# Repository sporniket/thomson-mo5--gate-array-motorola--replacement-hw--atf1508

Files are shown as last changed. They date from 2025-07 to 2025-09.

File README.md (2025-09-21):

# Replacement of the Motorola gate array for the Thomson MO5 by Microchip ATF1508

> [WARNING] Please read carefully this note before using this project. It contains important facts.

Content

1. What is **Replacement of the Motorola gate array for the Thomson MO5 by Microchip ATF1508**, and when to use it ?
2. What should you know before using **Replacement of the Motorola gate array for the Thomson MO5 by Microchip ATF1508** ?
3. How to use **Replacement of the Motorola gate array for the Thomson MO5 by Microchip ATF1508** ?
4. Known issues
5. Miscellanous

## 1. What is **Replacement of the Motorola gate array for the Thomson MO5 by Microchip ATF1508**, and when to use it ?

**Replacement of the Motorola gate array for the Thomson MO5 by Microchip ATF1508** is a hardware project to replace the original Motorola Gate Array of the Thomson MO5 8-bit computer, using an ATF1508.

### Licence

**Replacement of the Motorola gate array for the Thomson MO5 by Microchip ATF1508** is published under the Creative Commons CC0 license. You can find a copy of the licence there : https://creativecommons.org/publicdomain/zero/1.0/legalcode

You can copy, modify, distribute and perform the work, even for commercial purposes, all without asking permission.

**Replacement of the Motorola gate array for the Thomson MO5 by Microchip ATF1508** is distributed in the hope that it will be useful, but WITHOUT ANY WARRANTY; without even the implied warranty of MERCHANTABILITY or FITNESS FOR A PARTICULAR PURPOSE.

### Release notes

#### Version 1.0.0

Initial release.

> Note : I did something with the 2×4 header connector footprint, believing that it would held better the connector, but it does not help at all, sorry. I will fix this when I have time, it is just a bit inconvenient.

## 2. What should you know before using **Replacement of the Motorola gate array for the Thomson MO5 by Microchip ATF1508** ?

**Replacement of the Motorola gate array for the Thomson MO5 by Microchip ATF1508** is made using Kicad.

> Do not use **Replacement of the Motorola gate array for the Thomson MO5 by Microchip ATF1508** if this project is not suitable for your project.

### Fusemap file to program the ATF1508

You will find the SVF file in the `fusemap` folder.

### Bill Of Material (BOM)

|Item|Quantity|Designators|Type|Reference|Manufacturer|Link|
|---|---|---|---|---|---|---|
|1|8|`C1`, `C2`, `C3`, `C4`, `C5`, `C6`, `C7`, `C8`|Capacitor 0.22uF SMD 0603|220nF 25VDC 0603|N/A|[lcsc](https://lcsc.com/product-detail/Multilayer-Ceramic-Capacitors-MLCC-SMD-SMT_YAGEO-CC0603JRX7R8BB224_C519574.html) [rs-particuliers](https://rs-particuliers.com/Product.aspx?Product=485771)|
|2|1|`J1`|Pin header 2×4 pitch 100 mils||N/A|[lcsc](https://lcsc.com/product-detail/Pin-Headers_Megastar-ZX-PZ2-54-2-4PZZ_C7501275.html)|
|3|1|`J2`|Pin stripes 9 pins and 8 pins, pitch 100 mils||N/A|[lcsc 9 pins](https://lcsc.com/product-detail/Pin-Headers_HCTL-PZ254-1-09-Z-C_C5156436.html) [lcsc 8 pins](https://lcsc.com/product-detail/Pin-Headers_HCTL-PZ254-1-08-Z-C_C5156435.html)|
|4|1|`J3`|Pin header 2×1 pitch 100 mils||N/A|[lcsc](https://lcsc.com/product-detail/Pin-Headers_XFCN-PZ254V-11-02P_C492401.html)|
|5|3|`R1`, `R2`, `R3`|Resistor 4K7 SMD 0603|Resistor Thick Film 0603 1% 4k7|N/A|[lcsc](https://lcsc.com/product-detail/Chip-Resistor-Surface-Mount_VISHAY-RCS06034K70FKEA_C2078630.html) [rs-particuliers](https://rs-particuliers.com/Product.aspx?Product=2432188)|
|6|1|`U1`|CPLD ATF1508AS|ATF1508AS-10AU100|Microchip|[lcsc](https://lcsc.com/product-detail/Programmable-Logic-Device-CPLDs-FPGAs_MICROCHIP-ATF1508AS-10AU100_C31179.html) [rs-particuliers](https://rs-particuliers.com/Product.aspx?Product=1773660)|

## 3. How to use **Replacement of the Motorola gate array for the Thomson MO5 by Microchip ATF1508** ?

### From sources

To get the latest available work, one must clone the git repository, build and install the package.

	git clone https://github.com/sporniket/thomson-mo5--gate-array-motorola--replacement-hw--atf1508.git

Then, open the project with Kicad.

## 4. Known issues
See the [project issues](https://github.com/sporniket/thomson-mo5--gate-array-motorola--replacement-hw--atf1508/issues) page.

## 5. Miscellanous

### Report issues
Use the [project issues](https://github.com/sporniket/thomson-mo5--gate-array-motorola--replacement-hw--atf1508/issues) page.

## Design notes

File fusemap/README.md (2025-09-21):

# SVF fusemap

Unfortunately, the VHDL project that reproduces the behaviour of the original 
gate-array is not publicly available. Only the resulting SVF file is given.

As a reference, the quartus file is also provided.

## Programming the ATF1508

### Hardware setup

I use an FT323H usb dongle and a JTAG link to perform the programming.

For easier handling, there is a project to hold the FT232H module, the gate-array replacement. And it has
a witness LED that blinks when the programming is succesful, driven by the E signal (1MHz clock generated
by the gate array).

See https://github.com/sporniket/thomson-mo5--gate-array-development-board

## Using openOCD 

```sh
openocd -f /usr/share/openocd/scripts/interface/ftdi/um232h.cfg \
  -c "adapter speed 400" \
  -c "transport select jtag" \
  -c "jtag newtap ATF1508AS tap -irlen 3 -expected-id 0x0150803f" \
  -c init \
  -c "svf gate-array--motorola.svf quiet progress" \
  -c "sleep 200" \
  -c shutdown
```

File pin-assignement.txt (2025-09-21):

Pin Name/Usage               : Location  : Dir.   : I/O Standard      : Voltage : I/O Bank  : User Assignment
-------------------------------------------------------------------------------------------------------------
RESERVED                     : 1         :        :                   :         :           :                
RESERVED                     : 2         :        :                   :         :           :                
VCCIO                        : 3         : power  :                   : 5.0V    :           :                
TDI                          : 4         : input  : TTL               :         :           : Y              
INILText                     : 5         : output : TTL               :         :           : Y              
RESERVED                     : 6         :        :                   :         :           :                
SYNLText                     : 7         : output : TTL               :         :           : Y              
RESERVED                     : 8         :        :                   :         :           :                
RESERVED                     : 9         :        :                   :         :           :                
RESERVED                     : 10        :        :                   :         :           :                
GND                          : 11        : gnd    :                   :         :           :                
nCASCOLext                   : 12        : output : TTL               :         :           : Y              
MAext[7]                     : 13        : output : TTL               :         :           : Y              
MAext[3]                     : 14        : output : TTL               :         :           : Y              
TMS                          : 15        : input  : TTL               :         :           : Y              
MAext[2]                     : 16        : output : TTL               :         :           : Y              
RESERVED                     : 17        :        :                   :         :           :                
VCCIO                        : 18        : power  :                   : 5.0V    :           :                
RESERVED                     : 19        :        :                   :         :           :                
MAext[1]                     : 20        : output : TTL               :         :           : Y              
MAext[0]                     : 21        : output : TTL               :         :           : Y              
nCASPText                    : 22        : output : TTL               :         :           : Y              
nRASext                      : 23        : output : TTL               :         :           : Y              
MAext[6]                     : 24        : output : TTL               :         :           : Y              
MAext[5]                     : 25        : output : TTL               :         :           : Y              
GND                          : 26        : gnd    :                   :         :           :                
MAext[4]                     : 27        : output : TTL               :         :           : Y              
RESERVED                     : 28        :        :                   :         :           :                
AdresseCPUext[12]            : 29        : input  : TTL               :         :           : Y              
AdresseCPUext[11]            : 30        : input  : TTL               :         :           : Y              
AdresseCPUext[10]            : 31        : input  : TTL               :         :           : Y              
AdresseCPUext[9]             : 32        : input  : TTL               :         :           : Y              
RESERVED                     : 33        :        :                   :         :           :                
VCCIO                        : 34        : power  :                   : 5.0V    :           :                
RESERVED                     : 35        :        :                   :         :           :                
AdresseCPUext[8]             : 36        : input  : TTL               :         :           : Y              
AdresseCPUext[7]             : 37        : input  : TTL               :         :           : Y              
GND                          : 38        : gnd    :                   :         :           :                
VCCINT                       : 39        : power  :                   : 5.0V    :           :                
RESERVED                     : 40        :        :                   :         :           :                
RESERVED                     : 41        :        :                   :         :           :                
AdresseCPUext[6]             : 42        : input  : TTL               :         :           : Y              
GND                          : 43        : gnd    :                   :         :           :                
AdresseCPUext[5]             : 44        : input  : TTL               :         :           : Y              
AdresseCPUext[4]             : 45        : input  : TTL               :         :           : Y              
AdresseCPUext[3]             : 46        : input  : TTL               :         :           : Y              
AdresseCPUext[2]             : 47        : input  : TTL               :         :           : Y              
AdresseCPUext[1]             : 48        : input  : TTL               :         :           : Y              
AdresseCPUext[0]             : 49        : input  : TTL               :         :           : Y              
DataCPUext[7]                : 50        : bidir  : TTL               :         :           : Y              
VCCIO                        : 51        : power  :                   : 5.0V    :           :                
DataCPUext[6]                : 52        : bidir  : TTL               :         :           : Y              
DataCPUext[5]                : 53        : bidir  : TTL               :         :           : Y              
DataCPUext[4]                : 54        : bidir  : TTL               :         :           : Y              
DataCPUext[3]                : 55        : bidir  : TTL               :         :           : Y              
DataCPUext[2]                : 56        : bidir  : TTL               :         :           : Y              
DataCPUext[1]                : 57        : bidir  : TTL               :         :           : Y              
DataCPUext[0]                : 58        : bidir  : TTL               :         :           : Y              
GND                          : 59        : gnd    :                   :         :           :                
RESERVED                     : 60        :        :                   :         :           :                
RESERVED                     : 61        :        :                   :         :           :                
TCK                          : 62        : input  : TTL               :         :           : Y              
RESERVED                     : 63        :        :                   :         :           :                
nCASEXText                   : 64        : output : TTL               :         :           : Y              
nEext                        : 65        : output : TTL               :         :           : Y              
VCCIO                        : 66        : power  :                   : 5.0V    :           :                
Eext                         : 67        : output : TTL               :         :           : Y              
Qext                         : 68        : output : TTL               :         :           : Y              
RESERVED                     : 69        :        :                   :         :           :                
nDATAVALIDext                : 70        : output : TTL               :         :           : Y              
RESERVED                     : 71        :        :                   :         :           :                
RESERVED                     : 72        :        :                   :         :           :                
TDO                          : 73        : output : TTL               :         :           : Y              
GND                          : 74        : gnd    :                   :         :           :                
AdresseCPUext[15]            : 75        : input  : TTL               :         :           : Y              
AdresseCPUext[14]            : 76        : input  : TTL               :         :           : Y              
AdresseCPUext[13]            : 77        : input  : TTL               :         :           : Y              
FormeExt                     : 78        : input  : TTL               :         :           : Y              
RnWext                       : 79        : input  : TTL               :         :           : Y              
nCSCOLext                    : 80        : input  : TTL               :         :           : Y              
RESERVED                     : 81        :        :                   :         :           :                
VCCIO                        : 82        : power  :                   : 5.0V    :           :                
RESERVED                     : 83        :        :                   :         :           :                
RESERVED                     : 84        :        :                   :         :           :                
StartUpResetExt              : 85        : input  : TTL               :         :           : N              
GND                          : 86        : gnd    :                   :         :           :                
H16Ext                       : 87        : input  : TTL               :         :           : Y              
GND+                         : 88        :        :                   :         :           :                
GND+                         : 89        :        :                   :         :           :                
GND+                         : 90        :        :                   :         :           :                
VCCINT                       : 91        : power  :                   : 5.0V    :           :                
RESERVED                     : 92        :        :                   :         :           :                
RESERVED                     : 93        :        :                   :         :           :                
nCSEXText                    : 94        : input  : TTL               :         :           : Y              
GND                          : 95        : gnd    :                   :         :           :                
nCSPText                     : 96        : input  : TTL               :         :           : Y              
nCKLPext                     : 97        : input  : TTL               :         :           : Y              
SYCLext                      : 98        : input  : TTL               :         :           : Y              
nPOINText                    : 99        : output : TTL               :         :           : Y              
nSUPLText                    : 100       : output : TTL               :         :           : Y

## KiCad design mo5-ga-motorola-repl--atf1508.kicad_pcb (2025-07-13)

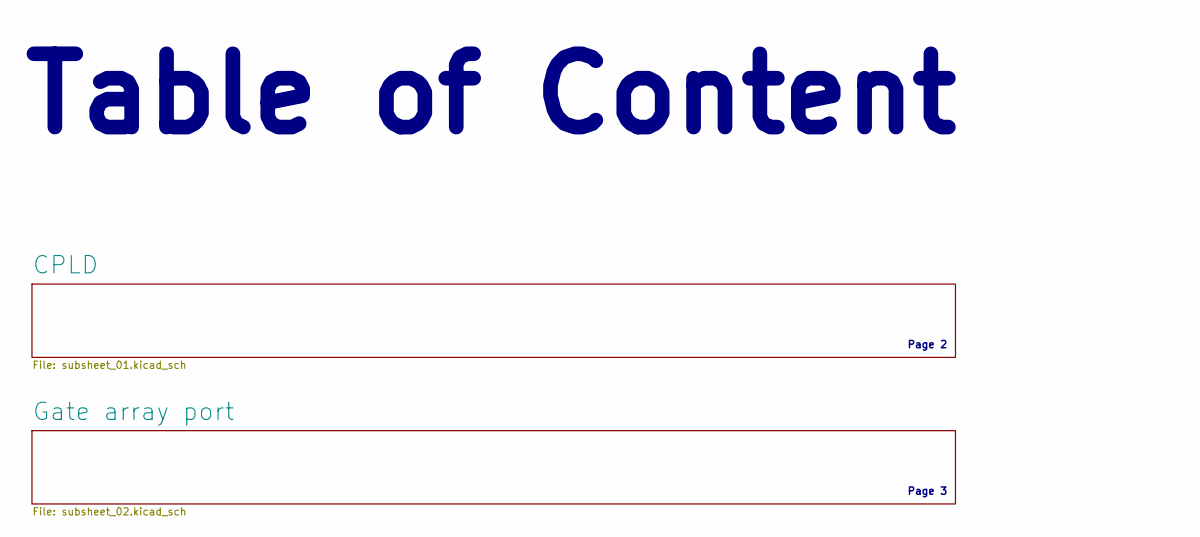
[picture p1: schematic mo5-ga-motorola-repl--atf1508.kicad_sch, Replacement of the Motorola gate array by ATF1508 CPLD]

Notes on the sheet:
Page 3
Page 2
Table of Content

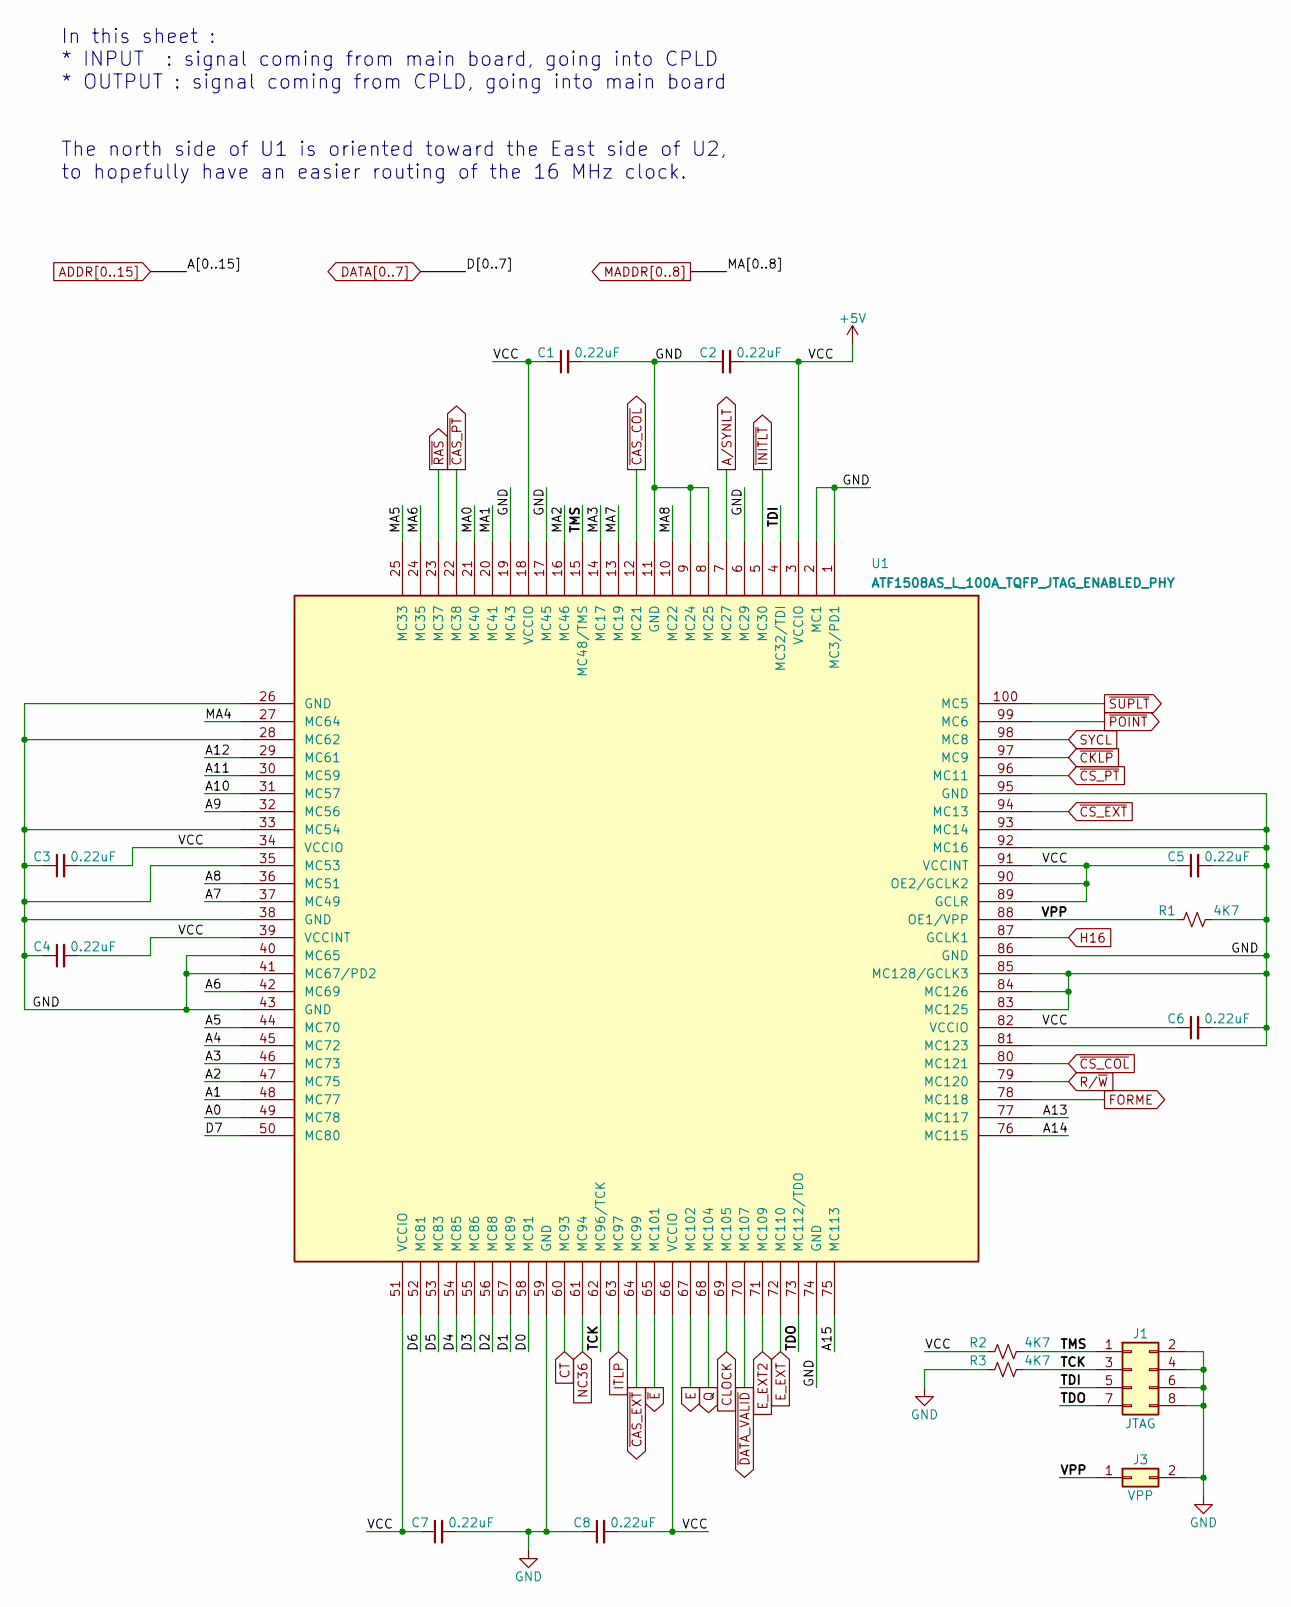
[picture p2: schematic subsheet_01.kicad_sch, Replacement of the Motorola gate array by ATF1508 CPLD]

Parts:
C1, C2, C3, C4, C5, C6, C7, C8: 0.22uF; C_0603_1608Metric_Pad1.08x0.95mm_HandSolder
J1: JTAG; PinHeader_2x04_P2.54mm_Vertical
J3: VPP; PinHeader_2x01_P2.54mm_Vertical
R1, R2, R3: 4K7; R_0603_1608Metric_Pad0.98x0.95mm_HandSolder
U1: ATF1508AS_L_100A_TQFP_JTAG_ENABLED_PHY; TQFP-100_14x14mm_P0.5mm

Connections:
+5V: C1.1, C2.2, C3.2, C4.2, C5.1, C6.1, C7.1, C8.2, R2.1, U1.3 (VCCIO), U1.18 (VCCIO), U1.34 (VCCIO), U1.39 (VCCINT), U1.51 (VCCIO), U1.66 (VCCIO), U1.82 (VCCIO), U1.89 (GCLR), U1.90 (OE2/GCLK2), U1.91 (VCCINT); also elsewhere on the board
/CPLD/TCK: J1.3, R3.2, U1.62 (MC96/TCK)
/CPLD/TDI: J1.5, U1.4 (MC32/TDI)
/CPLD/TDO: J1.7, U1.73 (MC112/TDO)
/CPLD/TMS: J1.1, R2.2, U1.15 (MC48/TMS)
/CPLD/VPP: J3.1, R1.1, U1.88 (OE1/VPP)
ADDR0: U1.49 (MC78); also elsewhere on the board
ADDR1: U1.48 (MC77); also elsewhere on the board
ADDR2: U1.47 (MC75); also elsewhere on the board
ADDR3: U1.46 (MC73); also elsewhere on the board
ADDR4: U1.45 (MC72); also elsewhere on the board
ADDR5: U1.44 (MC70); also elsewhere on the board
ADDR6: U1.42 (MC69); also elsewhere on the board
ADDR7: U1.37 (MC49); also elsewhere on the board
ADDR8: U1.36 (MC51); also elsewhere on the board
ADDR9: U1.32 (MC56); also elsewhere on the board
ADDR10: U1.31 (MC57); also elsewhere on the board
ADDR11: U1.30 (MC59); also elsewhere on the board
ADDR12: U1.29 (MC61); also elsewhere on the board
ADDR13: U1.77 (MC117); also elsewhere on the board
ADDR14: U1.76 (MC115); also elsewhere on the board
ADDR15: U1.75 (MC113); also elsewhere on the board
A/SYNLT: U1.7 (MC27); also elsewhere on the board
CLOCK: U1.69 (MC105); also elsewhere on the board
CT: U1.60 (MC93); also elsewhere on the board
DATA0: U1.58 (MC91); also elsewhere on the board
DATA1: U1.57 (MC89); also elsewhere on the board
DATA2: U1.56 (MC88); also elsewhere on the board
DATA3: U1.55 (MC86); also elsewhere on the board
DATA4: U1.54 (MC85); also elsewhere on the board
DATA5: U1.53 (MC83); also elsewhere on the board
DATA6: U1.52 (MC81); also elsewhere on the board
DATA7: U1.50 (MC80); also elsewhere on the board
E: U1.67 (MC102); also elsewhere on the board
E_EXT: U1.72 (MC110); also elsewhere on the board
E_EXT2: U1.71 (MC109); also elsewhere on the board
FORME: U1.78 (MC118); also elsewhere on the board
GND: C1.2, C2.1, C3.1, C4.1, C5.2, C6.2, C7.2, C8.1, J1.2, J1.4, J1.6, J1.8, J3.2, R1.2, R3.1, U1.1 (MC3/PD1), U1.2 (MC1), U1.6 (MC29), U1.8 (MC25), U1.9 (MC24), U1.11 (GND), U1.17 (MC45), U1.19 (MC43), U1.26 (GND), U1.28 (MC62), U1.33 (MC54), U1.35 (MC53), U1.38 (GND), U1.40 (MC65), U1.41 (MC67/PD2), U1.43 (GND), U1.59 (GND), U1.74 (GND), U1.81 (MC123), U1.83 (MC125), U1.84 (MC126), U1.85 (MC128/GCLK3), U1.86 (GND), U1.92 (MC16), U1.93 (MC14), U1.95 (GND); also elsewhere on the board
H16: U1.87 (GCLK1); also elsewhere on the board
ITLP: U1.63 (MC97); also elsewhere on the board
MADDR0: U1.21 (MC40); also elsewhere on the board
MADDR1: U1.20 (MC41); also elsewhere on the board
MADDR2: U1.16 (MC46); also elsewhere on the board
MADDR3: U1.14 (MC17); also elsewhere on the board
MADDR4: U1.27 (MC64); also elsewhere on the board
MADDR5: U1.25 (MC33); also elsewhere on the board
MADDR6: U1.24 (MC35); also elsewhere on the board
MADDR7: U1.13 (MC19); also elsewhere on the board
MADDR8: U1.10 (MC22); also elsewhere on the board
NC36: U1.61 (MC94); also elsewhere on the board
Q: U1.68 (MC104); also elsewhere on the board
R/~W: U1.79 (MC120); also elsewhere on the board
SYCL: U1.98 (MC8); also elsewhere on the board
~CAS_COL: U1.12 (MC21); also elsewhere on the board
~CAS_EXT: U1.64 (MC99); also elsewhere on the board
~CAS_PT: U1.22 (MC38); also elsewhere on the board
~CKLP: U1.97 (MC9); also elsewhere on the board
~CS_COL: U1.80 (MC121); also elsewhere on the board
~CS_EXT: U1.94 (MC13); also elsewhere on the board
~CS_PT: U1.96 (MC11); also elsewhere on the board
~DATA_VALID: U1.70 (MC107); also elsewhere on the board
~E: U1.65 (MC101); also elsewhere on the board
~INITLT: U1.5 (MC30); also elsewhere on the board
~POINT: U1.99 (MC6); also elsewhere on the board
~RAS: U1.23 (MC37); also elsewhere on the board
~SUPLT: U1.100 (MC5); also elsewhere on the board

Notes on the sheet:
In this sheet : * INPUT : signal coming from main board, going into CPLD * OUTPUT : signal coming from CPLD, going into main board
The north side of U1 is oriented toward the East side of U2, to hopefully have an easier routing of the 16 MHz clock.

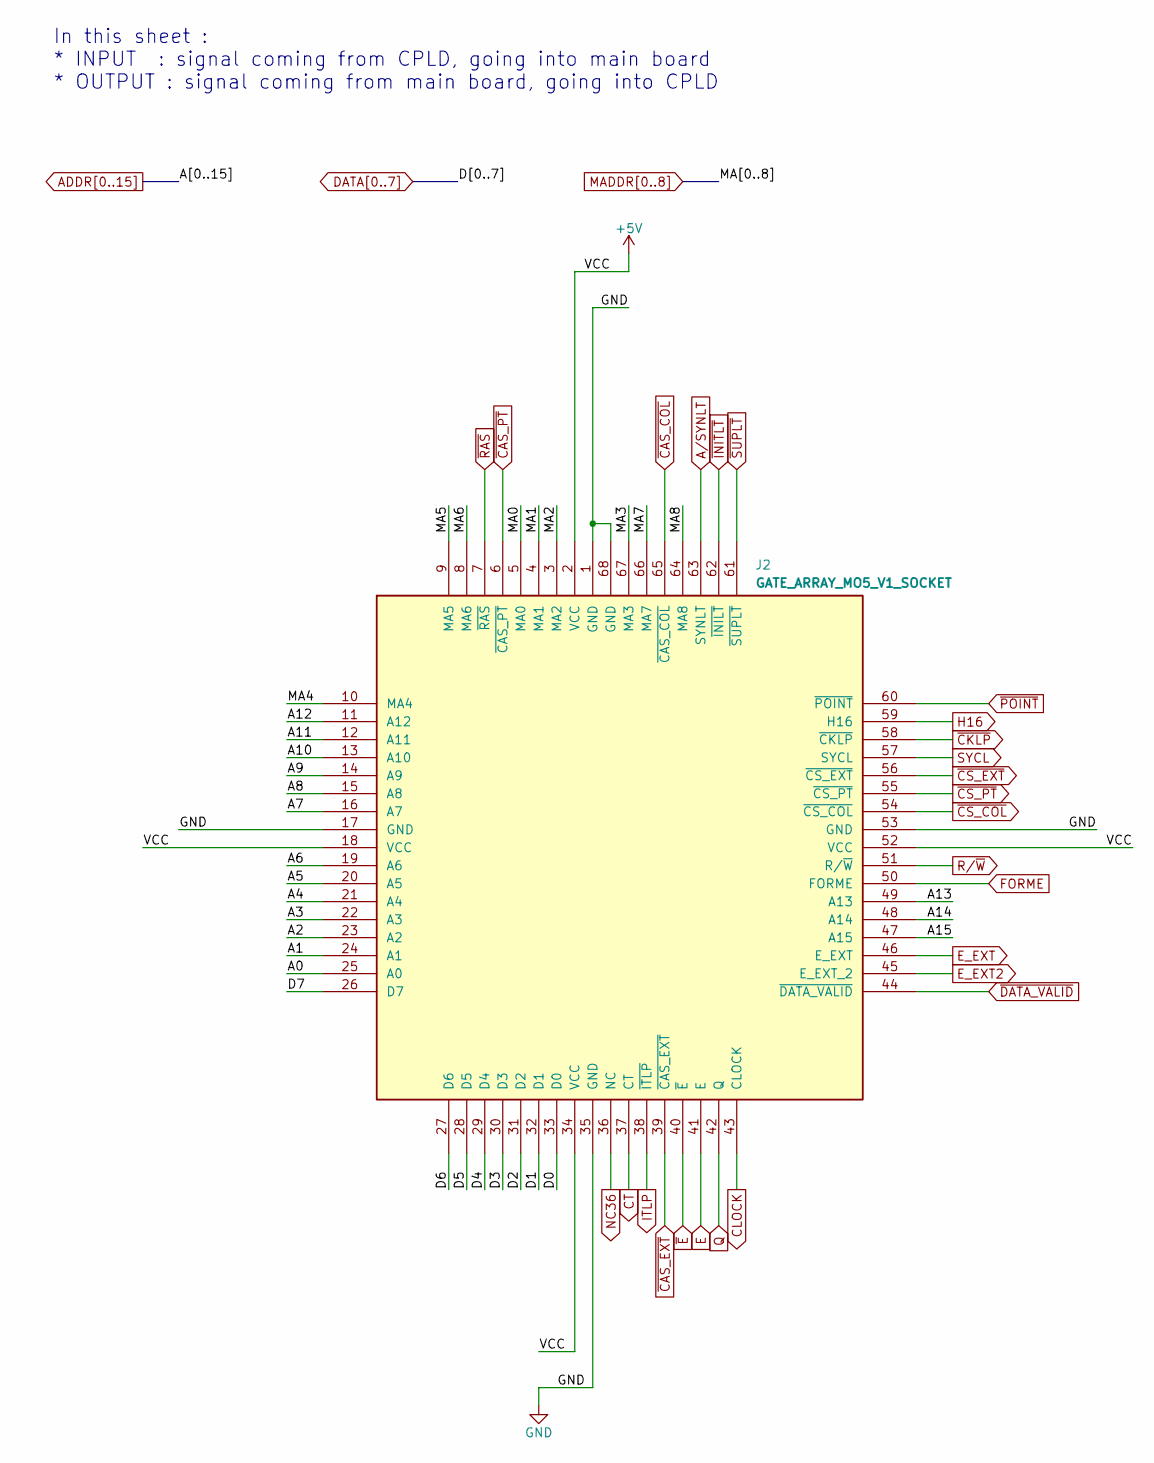
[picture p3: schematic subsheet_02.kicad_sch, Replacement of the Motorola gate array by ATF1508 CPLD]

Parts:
J2: GATE_ARRAY_MO5_V1_SOCKET; gate_array_plcc68_staggered

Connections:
+5V: J2.2 (VCC), J2.18 (VCC), J2.34 (VCC), J2.52 (VCC); also elsewhere on the board
ADDR0: J2.25 (A0); also elsewhere on the board
ADDR1: J2.24 (A1); also elsewhere on the board
ADDR2: J2.23 (A2); also elsewhere on the board
ADDR3: J2.22 (A3); also elsewhere on the board
ADDR4: J2.21 (A4); also elsewhere on the board
ADDR5: J2.20 (A5); also elsewhere on the board
ADDR6: J2.19 (A6); also elsewhere on the board
ADDR7: J2.16 (A7); also elsewhere on the board
ADDR8: J2.15 (A8); also elsewhere on the board
ADDR9: J2.14 (A9); also elsewhere on the board
ADDR10: J2.13 (A10); also elsewhere on the board
ADDR11: J2.12 (A11); also elsewhere on the board
ADDR12: J2.11 (A12); also elsewhere on the board
ADDR13: J2.49 (A13); also elsewhere on the board
ADDR14: J2.48 (A14); also elsewhere on the board
ADDR15: J2.47 (A15); also elsewhere on the board
A/SYNLT: J2.63 (SYNLT); also elsewhere on the board
CLOCK: J2.43 (CLOCK); also elsewhere on the board
CT: J2.37 (CT); also elsewhere on the board
DATA0: J2.33 (D0); also elsewhere on the board
DATA1: J2.32 (D1); also elsewhere on the board
DATA2: J2.31 (D2); also elsewhere on the board
DATA3: J2.30 (D3); also elsewhere on the board
DATA4: J2.29 (D4); also elsewhere on the board
DATA5: J2.28 (D5); also elsewhere on the board
DATA6: J2.27 (D6); also elsewhere on the board
DATA7: J2.26 (D7); also elsewhere on the board
E: J2.41 (E); also elsewhere on the board
E_EXT: J2.46 (E_EXT); also elsewhere on the board
E_EXT2: J2.45 (E_EXT_2); also elsewhere on the board
FORME: J2.50 (FORME); also elsewhere on the board
GND: J2.1 (GND), J2.17 (GND), J2.35 (GND), J2.53 (GND), J2.68 (GND); also elsewhere on the board
H16: J2.59 (H16); also elsewhere on the board
ITLP: J2.38 (~ITLP); also elsewhere on the board
MADDR0: J2.5 (MA0); also elsewhere on the board
MADDR1: J2.4 (MA1); also elsewhere on the board
MADDR2: J2.3 (MA2); also elsewhere on the board
MADDR3: J2.67 (MA3); also elsewhere on the board
MADDR4: J2.10 (MA4); also elsewhere on the board
MADDR5: J2.9 (MA5); also elsewhere on the board
MADDR6: J2.8 (MA6); also elsewhere on the board
MADDR7: J2.66 (MA7); also elsewhere on the board
MADDR8: J2.64 (MA8); also elsewhere on the board
NC36: J2.36 (NC); also elsewhere on the board
Q: J2.42 (Q); also elsewhere on the board
R/~W: J2.51 (R/~W); also elsewhere on the board
SYCL: J2.57 (SYCL); also elsewhere on the board
~CAS_COL: J2.65 (~CAS_COL); also elsewhere on the board
~CAS_EXT: J2.39 (~CAS_EXT); also elsewhere on the board
~CAS_PT: J2.6 (~CAS_PT); also elsewhere on the board
~CKLP: J2.58 (~CKLP); also elsewhere on the board
~CS_COL: J2.54 (~CS_COL); also elsewhere on the board
~CS_EXT: J2.56 (~CS_EXT); also elsewhere on the board
~CS_PT: J2.55 (~CS_PT); also elsewhere on the board
~DATA_VALID: J2.44 (~DATA_VALID); also elsewhere on the board
~E: J2.40 (~E); also elsewhere on the board
~INITLT: J2.62 (~INILT); also elsewhere on the board
~POINT: J2.60 (~POINT); also elsewhere on the board
~RAS: J2.7 (~RAS); also elsewhere on the board
~SUPLT: J2.61 (~SUPLT); also elsewhere on the board

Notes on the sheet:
In this sheet : * INPUT : signal coming from CPLD, going into main board * OUTPUT : signal coming from main board, going into CPLD

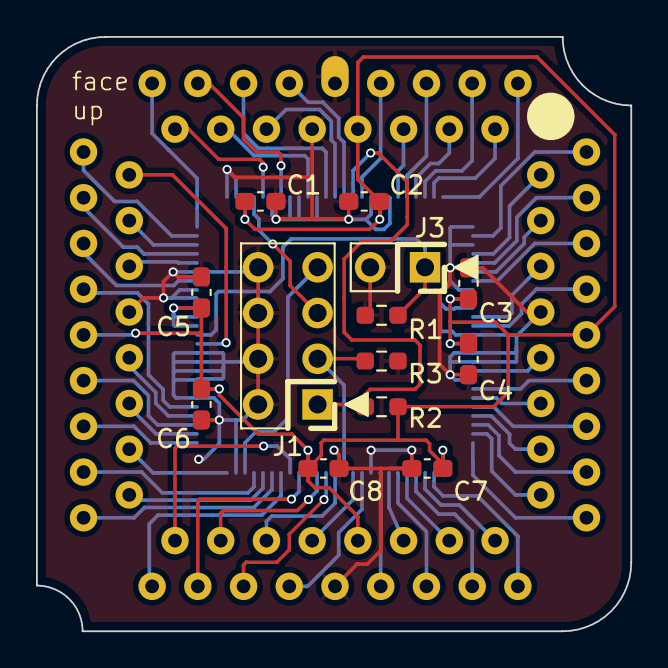
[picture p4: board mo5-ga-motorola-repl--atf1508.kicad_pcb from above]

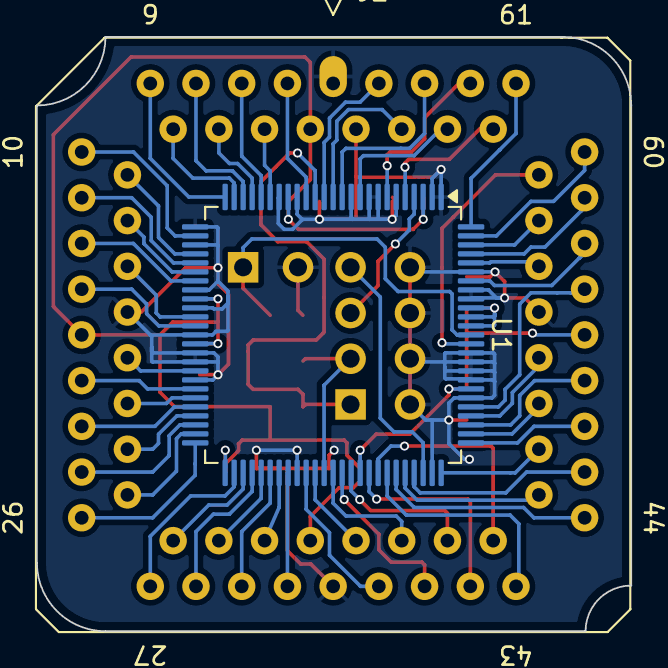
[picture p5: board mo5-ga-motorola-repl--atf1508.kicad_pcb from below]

Board: 4 copper layers, 33.0 x 33.0 mm, 15 parts (2 on the bottom side), 66 nets.

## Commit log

2025-05-17 Initialize the schematic : main and sub sheets, cartridge, page layout
    [mo5-ga-motorola-repl--atf1508.kicad_pcb, mo5-ga-motorola-repl--atf1508.kicad_sch, subsheet_01.kicad_sch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]
2025-05-17 schematic : place U1 and U2, the CPLD and the Gate array connector
    [subsheet_01.kicad_sch, subsheet_02.kicad_sch]
2025-05-17 schematic : setup all signals going through U2
    [subsheet_02.kicad_sch]
2025-05-17 schematic : U2 renamed to J2
    [subsheet_02.kicad_sch]
2025-05-17 schematics : put power symbols
    [subsheet_02.kicad_sch]
2025-05-17 schematic : done U1, decoupling capacitors, pull resistors, JTAG and VPP connectors
    [subsheet_01.kicad_sch]
2025-05-18 schematics : format text size for subsheet name in main sheet
    [mo5-ga-motorola-repl--atf1508.kicad_sch]
2025-05-24 pcb : draft
    [mo5-ga-motorola-repl--atf1508.kicad_pcb, subsheet_01.kicad_sch, subsheet_02.kicad_sch]
2025-05-24 pcb : adjusting
    [mo5-ga-motorola-repl--atf1508.kicad_pcb]
2025-05-25 pcb : slowly adjusting traces
    [mo5-ga-motorola-repl--atf1508.kicad_pcb]
2025-05-25 pcb : adjusting traces
    [mo5-ga-motorola-repl--atf1508.kicad_pcb]
2025-05-31 pcb/schematics : rework connexion for easier routing, pcb edge, power distribution network
    [mo5-ga-motorola-repl--atf1508.kicad_pcb, subsheet_01.kicad_sch]
2025-07-13 prepare release
    [mo5-ga-motorola-repl--atf1508.kicad_pcb, mo5-ga-motorola-repl--atf1508.kicad_sch, subsheet_01.kicad_sch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]
2025-07-13 tweak CI setup to remove errors caused by standard QFP footprint
2025-07-16 Put BOM in readme
2025-07-16 tweaked BOM in README for display
2025-09-21 added fusemap and some information
